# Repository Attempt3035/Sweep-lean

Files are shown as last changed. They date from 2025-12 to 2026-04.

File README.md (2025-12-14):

# Sweep
<!--
           ___                        ___
      ___ |   | ___ ___      ___ ___ |   | ___
 ___ |   |`___`|   |   |    |   |   |`___`|   | ___
|   |`___`|   |`___`___`    `___`___`|   |`___`|   |
`___`|   |`___`|   |   |    |   |   |`___`|   |`___`
|   |`___`|   |`___`___`    `___`___`|   |`___`|   |
`___`|   |`___`|   |   |    |   |   |`___`|   |`___`
|   |`___`     `___`___`    `___`___`     `___`|   |
`___`           ___ ___      ___ ___           `___`
               |   |   |    |   |   |
               `___`___`    `___`___`
-->
>  sweep-hero  
> <sub>Bluetooth Sweep 2 + MBK Legend Keycaps</sub>

<span>
  <a href="https://discord.gg/czXcTXbsgU">
    
  </a>
  
  
  
</span>

## What is sweep?

Sweep is a version of the more fabulous [Ferris](https://github.com/pierrechevalier83/ferris) by [Pierre Chevalier](https://github.com/pierrechevalier83/) that uses a daughter board like a promicro, elite-c, bit-c, nice!nano etc. instead of using onboard components.

## What are the different types?

⭐ Sweep 2 - Recommended Choc v1 board with all the features.  
⭕ Sweep Half Swept - Same as Sweep 2, but with a reversible pro-micro footprint.  
⭕ Sweep Bling MX - An MX only Sweep that features Kailh's hotswap sockets and a stacked case.  
⭕ Sweep Bling LP - A Choc v1 only Sweep that features Kailh's hotswap sockets.  
⭕ Sweep High - Same as the Sweep 2, but trades choc spacing for compatibility with more switches and keycaps.  
⭕ Sweep High M - A soldered MX only Sweep, with a reversible PCB design.  
⭕ Sweep Mini - The only version that supports Choc minis.  

| Device | On/Off Switch<sup>[1]</sup> | Reversible PCB<sup>[2]</sup> | Choc V1 | Choc V2 | Choc Mini | MX & Alps | Choc Spacing<sup>[3]</sup> | Tenting<sup>[4]</sup> | Hot Swap |
| :--- | :---: | :---: | :---: | :---: | :---: | :---: | :---: | :---: | :---: |
| Sweep2.x | ✔ | | ✔ | | | | ✔ | ✔ | Mill-Max (optional) |
| Sweep Bling LP | ✔ | | ✔ | | | | ✔ | ✔ | Kailh (required) |
| Sweep Bling MX | ✔ | ✔ | | | | ⚠<br/><sup>[5]</sup> | | ✔ | Kailh (required) |
| Sweep High | ✔ | | ✔ | ✔ | | ✔ | | ✔ |
| Sweep High M | ✔ | ✔ | | | | MX | | ✔ | |
| Sweep Half Swept  | ✔ | ✔ | ✔ | | | | ✔ | ✔ | Mill-Max (optional) |
| Sweep Mini | | ✔ | | | ✔ | | ✔ | |

> Note: All versions support bluetooth with Nice!Nano

*<sup>[1]</sup> An on/off switch is recommended for bluetooth builds.*  
*<sup>[2]</sup> With a reversible PCB it's easier to make mistakes during assembly, but it allows you to purchase less boards.*  
*<sup>[3]</sup> Choc spaced boards have the switches in a tighter grid. This provides a better final look but is only compatible with some choc keycaps. (e.g. MBK)*  
*<sup>[4]</sup> Supports splitkb's [tenting puck.](https://splitkb.com/products/tenting-puck?_pos=1&_psq=tenting%20&_ss=e&_v=1.0)*  
*<sup>[5]</sup> MX + kailh hotswap ONLY. Alps are NOT supported.*  

## Components list

To build and use a Sweep you will need:

* 1x PCB Kit
* 2x promicro compatible boards or 2 nice!nanos.
* 34 switches of a compatible type (refer to the compatibility table)
* 34 keycaps
* 2x reset switches (optional; [B3U-1000P(M)](https://github.com/davidphilipbarr/Sweep/issues/20))
* Some little rubber feet/bumpers
* 2x power switches (optional if supported; MSK 12C02)
* 1x TRRS (not TRS!) cable (wired build only)
* 2x TRRS Jack [PJ-320A] (wired build only)
* 1 USB Cable (depends on your micro-controller choice)

## How do I make this thing?

<a href="https://www.youtube.com/watch?v=fBPu7AyDtkM" target="_blank">
  
</a>

## Firmware

The firmware can be found [with the Ferris  firmware as part of QMK](https://github.com/qmk/qmk_firmware/tree/master/keyboards/ferris/sweep).

Firmware for zmk and bluemicro_ble is called ["Cradio"](https://zmk.dev/docs/hardware/).

## Who made this?

* [Pierre Chevalier](https://github.com/pierrechevalier83)
* [David Barr](https://github.com/davidphilipbarr)
* [Ibnu Daru Aji](https://github.com/ibnuda/)
* [Duccio](https://github.com/duckyb)

## Featured Forks ✨

* [Sweep Gateron](https://github.com/drewlwhitney/Sweep-Gateron) by drewlwhitney: *A Sweep High modded with Gateron-LP KS-33 support.*

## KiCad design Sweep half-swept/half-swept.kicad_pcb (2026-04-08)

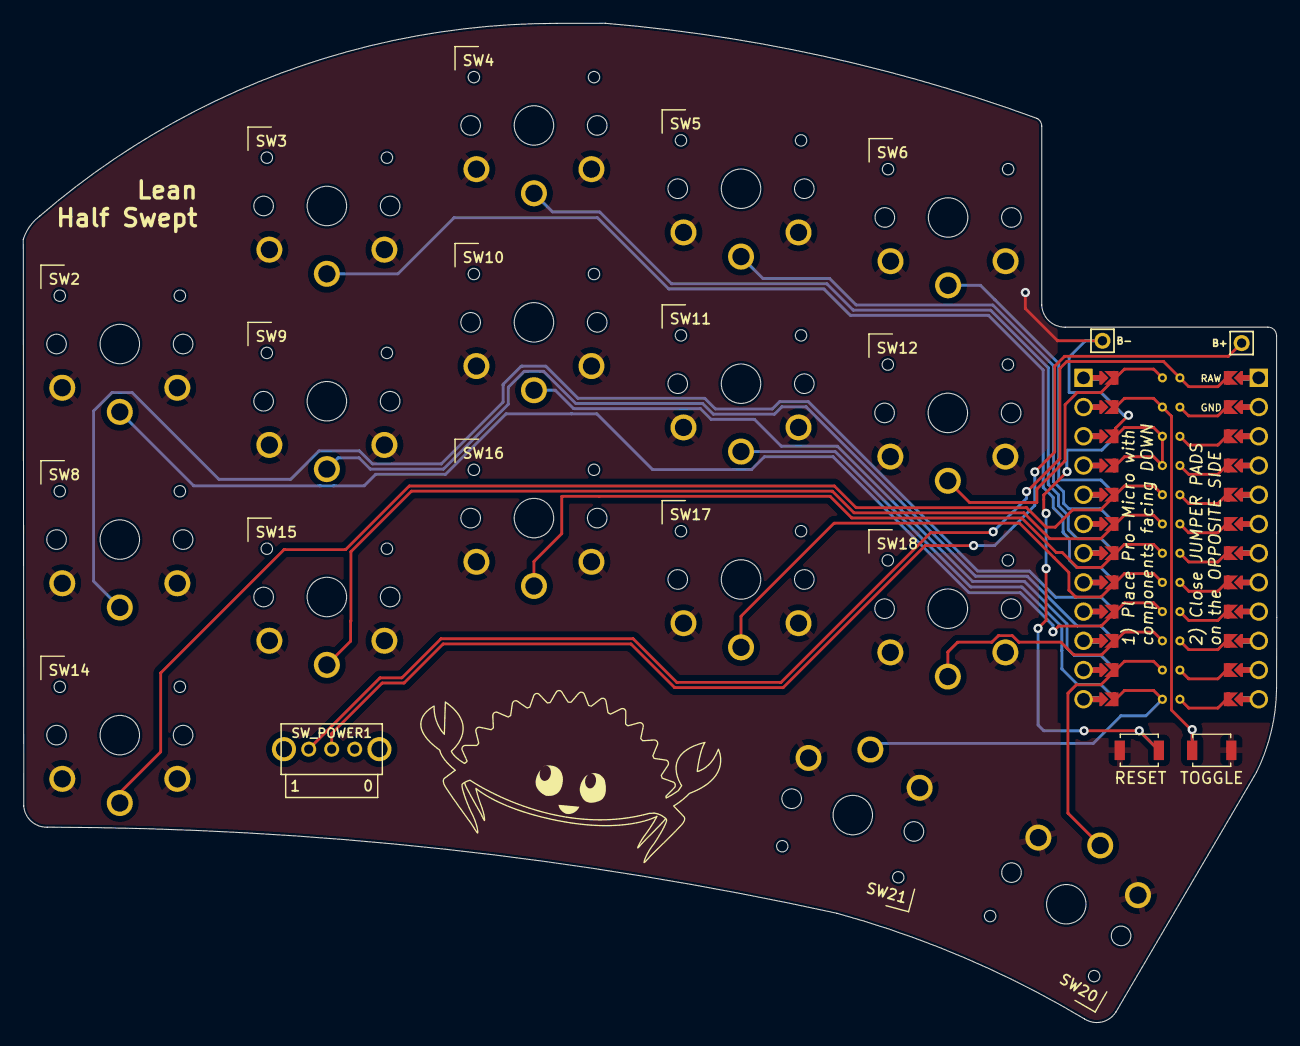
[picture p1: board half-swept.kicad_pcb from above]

Board: 2 copper layers, 109.0 x 86.9 mm, 23 parts (0 on the bottom side), 22 nets.

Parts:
B+: MountingHole_Pad; 1pin_conn
B-: MountingHole_Pad; 1pin_conn
RSW2, RSW4: SW_Push; Tactile-Switch_SMT
SW2, SW3, SW4, SW5, SW6, SW8, SW9, SW10, SW11, SW12, SW14, SW15, SW16, SW17, SW18, SW20, SW21: SW_Push; SW_PG1350_rev_DPB
SW_POWER1: SK12D07VG4
U1: ProMicro-kbd; ProMicro_jumpers_facedown

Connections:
BT+: B+.1, SW_POWER1.COM
Switch1: SW2.1, U1.9 (D7)
Switch2: SW3.1, U1.17 (F7)
Switch3: SW4.1, U1.18 (F6)
Switch4: SW5.1, U1.19 (F5)
Switch5: SW6.1, U1.20 (F4)
Switch6: SW8.1, U1.16 (B1)
Switch7: SW9.1, U1.15 (B3)
Switch8: SW10.1, U1.14 (B2)
Switch9: SW11.1, U1.13 (B6)
Switch10: SW12.1, U1.1 (TX)
Switch11: SW14.1, U1.5 (SDA)
Switch12: SW15.1, U1.6 (SCL)
Switch13: SW16.1, U1.7 (D4)
Switch14: SW17.1, U1.8 (C6)
Switch15: SW18.1, U1.10 (E6)
Switch16: SW20.1, U1.11 (B4)
Switch17: SW21.1, U1.12 (B5)
Switch18: RSW4.1, RSW4.2, U1.2 (RX)
gnd: B-.1, RSW2.1, RSW2.2, RSW4.1, RSW4.2, SW2.2, SW3.2, SW4.2, SW5.2, SW6.2, SW8.2, SW9.2, SW10.2, SW11.2, SW12.2, SW14.2, SW15.2, SW16.2, SW17.2, SW18.2, SW20.2, SW21.2, U1.3 (GND), U1.4 (GND), U1.23 (GND)
raw: SW_POWER1.1, U1.24 (RAW)
reset: RSW2.1, RSW2.2, U1.22 (RST)
